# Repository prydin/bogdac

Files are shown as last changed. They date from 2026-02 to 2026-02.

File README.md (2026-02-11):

# BogDAC - A no frills DAC board for ES9039Q2M

## Introduction
I like to keep things simple. Reading about people "improving" their DACs with femtosecond-precision clocks, re-clockers, hundreds of farads of capacitance and potting soil (yes, potting soil), I decided I wanted to create a bog standard
DAC board based on the ES9039Q2M chip. I wanted a small board that would just accept an I2S stream and I2C commands and output single-ended audio. 

## Design Overview
This is following my Bog Standard concept: Keep things simple, follow best practices and avoid audiophile fads. The chip is locked into software mode and asynchronous I2S (a.k.a. PCM) operations using a local 49.152MHz oscillator. This 
allows for a design with a very simple and short clock signal path and should (at least in my opinion) perform better than external clocks connected through wires. The output section is pretty much just the one suggested in the data sheet and
based on OPA1612. The +/- 12V power for the analog section is provided by a TPS7A39 regulator. The 3.3V power for the analog reference voltages and the digital power is fed by a LT3046 regulator. The L3046 can be fed either from a separate 5V
power input or from the 12V rail by installing a jumper. Please note that nothing should be plugged into the 5V inlet if the jumper is installed.

## Schematic
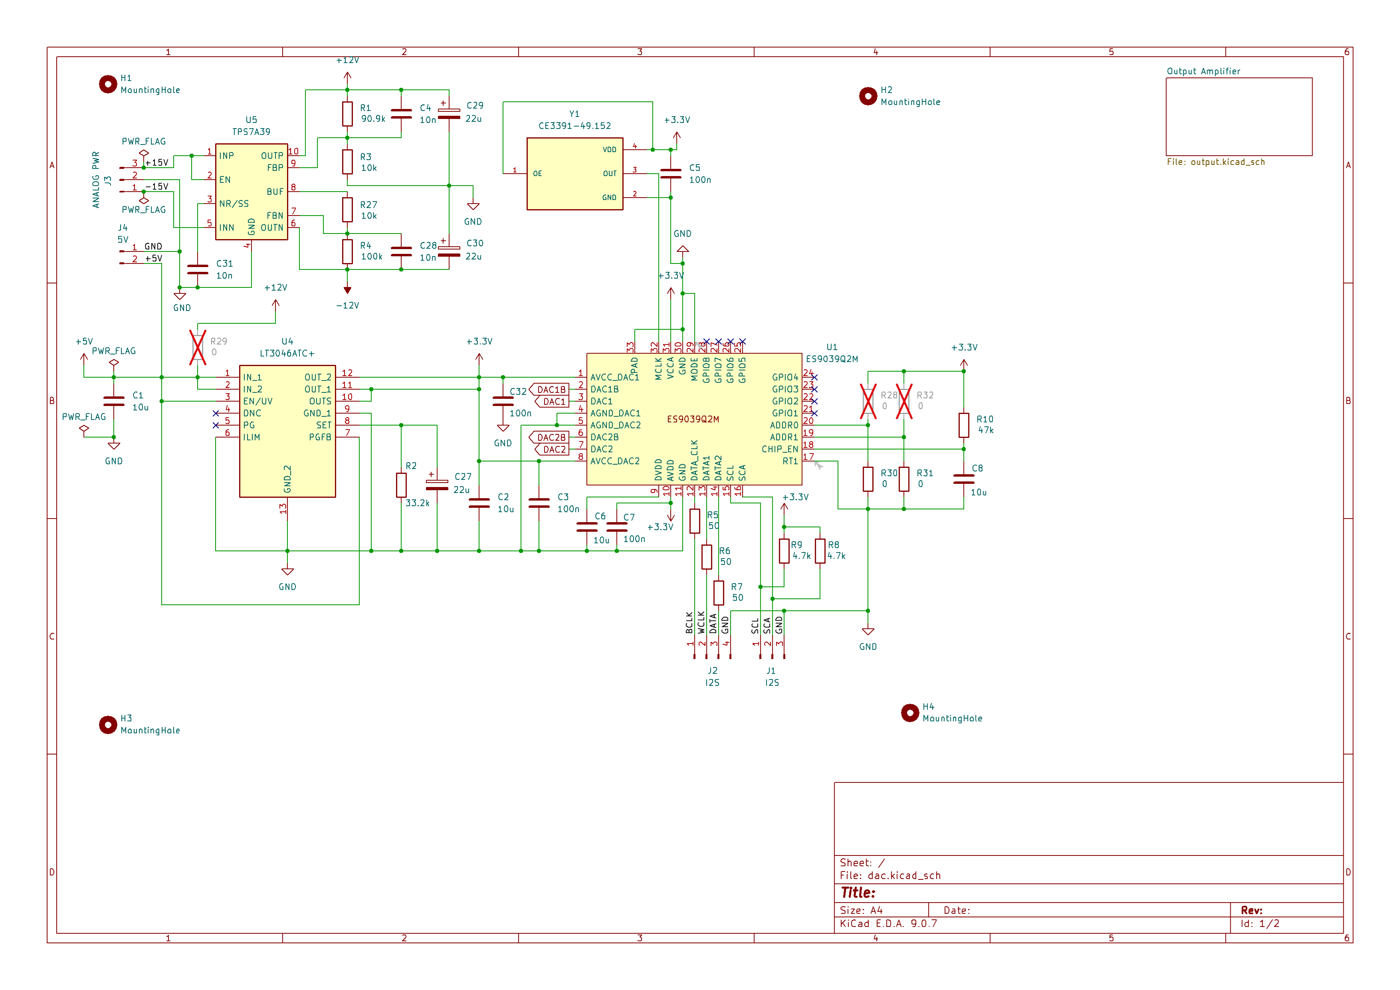
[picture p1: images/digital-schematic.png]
Digital schematic

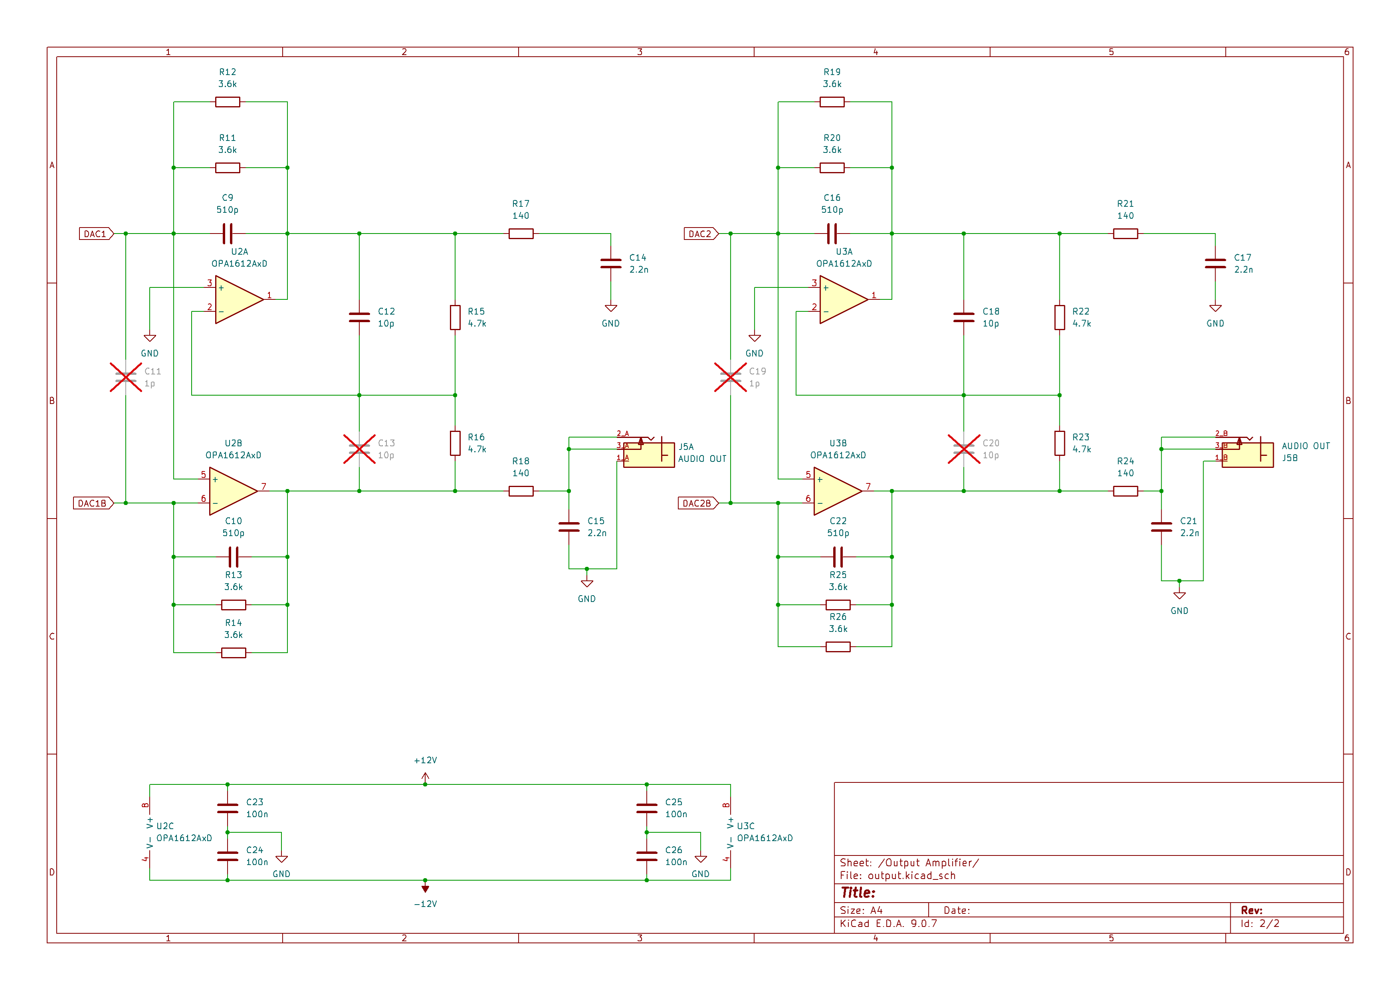
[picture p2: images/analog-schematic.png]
Analog schematic


## Test results
I tested this using a QA403. While this is a superb piece of gear, it has its limitations compared to test equipment that costs 100 times more. Because of this, the lower bound of the THD I can measure is about 0.0001% and the lowest noise 
floor is just above -150dBV. In fact, the harmonic profile of a loopback measurement looks very similar to the results I'm getting, so my hypothesis is that almost all noise and distortion you see comes from the measurement setup and 
not the circuit.

A 1kHz tone at full volume yields this spectrum. The THD is about 0.00013# and the SNR sits at about 113dB. I think the actual numbers are a lot better. Anyone who wants to lend me a $50,000 audio analyzer? :)


Another interesting measurement is looking at the idle noise. This is the DAC fully enabled, but without an input signal. I'm running the board on a cheap lab supply. As you can see, there's virtually no hum and very low noise.
You can thank those fancy regulators for that! 


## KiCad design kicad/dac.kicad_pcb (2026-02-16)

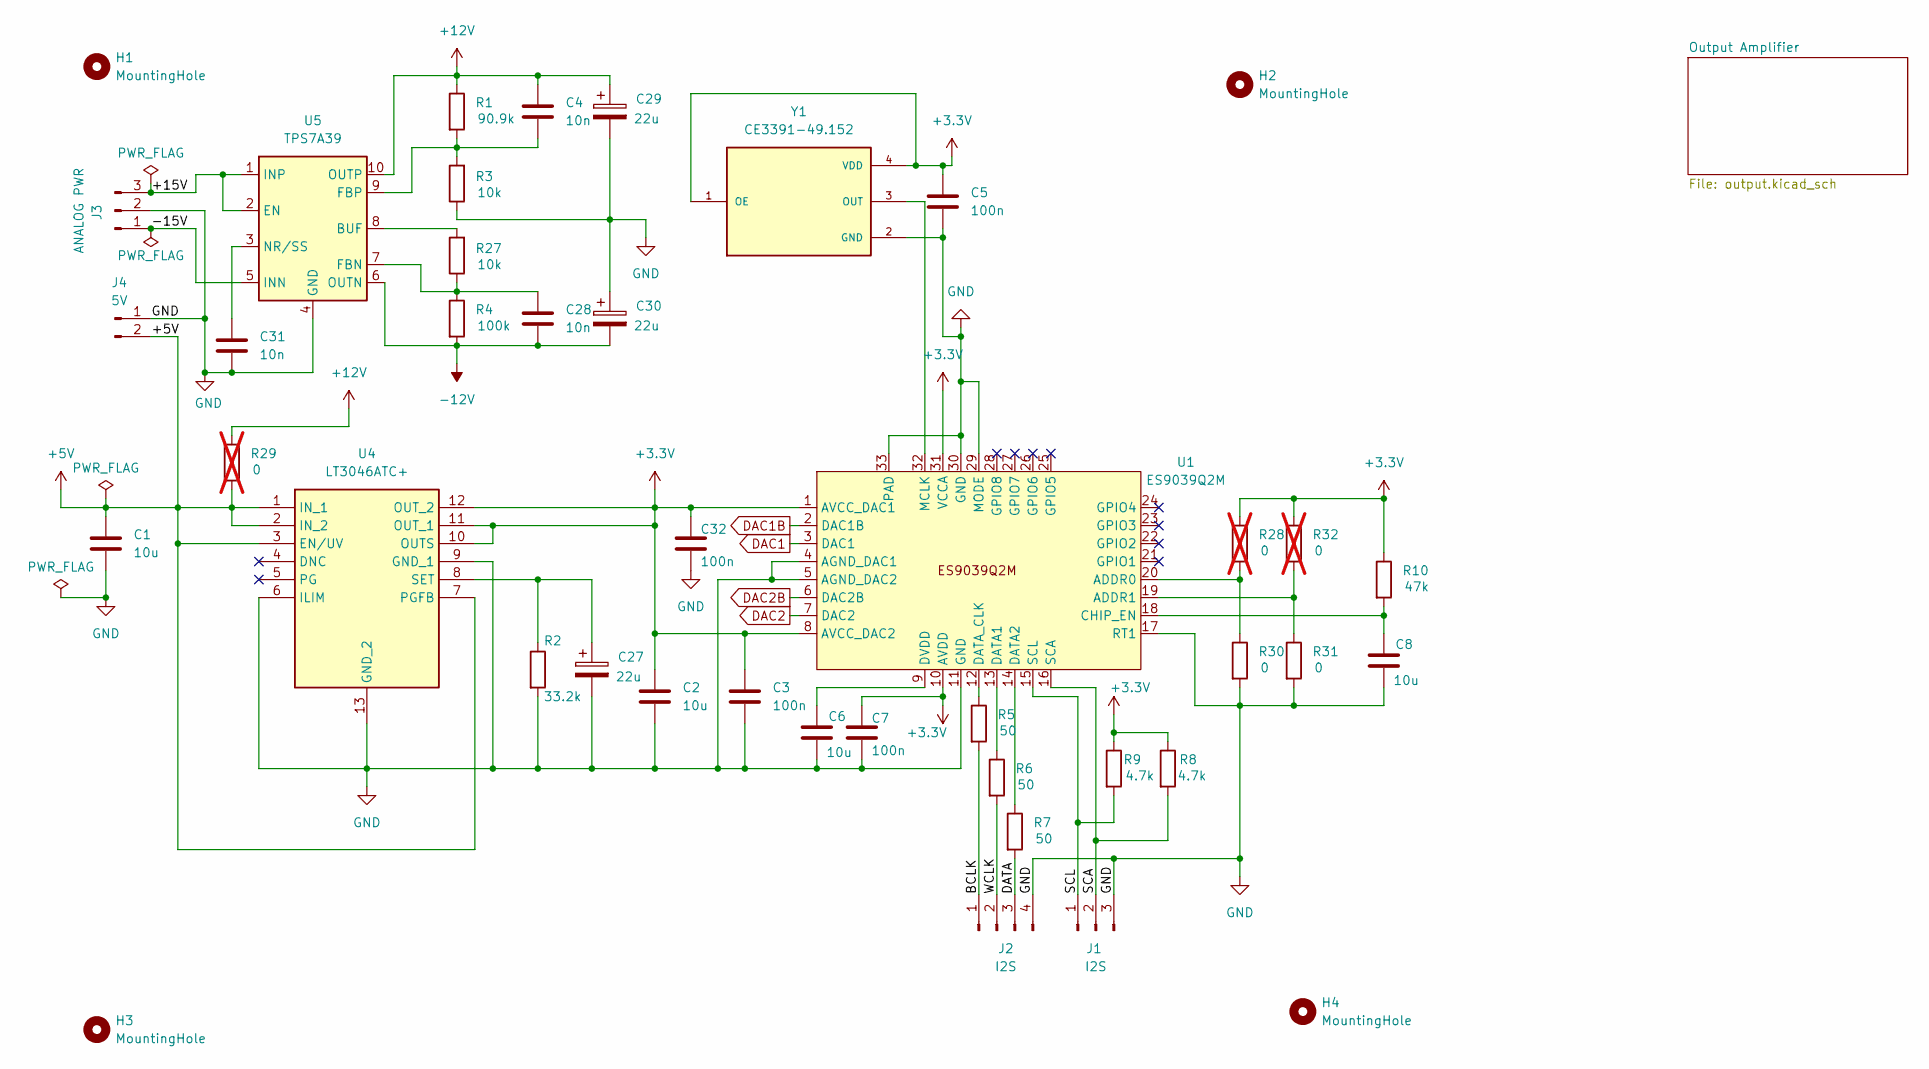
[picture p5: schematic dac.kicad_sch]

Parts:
C1, C2, C6, C8: 10u; C_0805_2012Metric
C3, C7, C32: 100n; C_0402_1005Metric
C4, C28, C31: 10n; C_0603_1608Metric
C5: 100n; C_0603_1608Metric
C27, C29, C30: 22u; CP_EIA-3216-10_Kemet-I_HandSolder
H1: MountingHole; MountingHole_3.2mm_M3
H2, H3, H4: MountingHole
J1: I2S; JST_PH_B3B-PH-K_1x03_P2.00mm_Vertical
J2: I2S; JST_PH_B4B-PH-K_1x04_P2.00mm_Vertical
J3: ANALOG PWR; JST_PH_B3B-PH-K_1x03_P2.00mm_Vertical
J4: 5V; JST_PH_B2B-PH-K_1x02_P2.00mm_Vertical
R1: 90.9k; R_0603_1608Metric_Pad0.98x0.95mm_HandSolder
R2: 33.2k; R_0603_1608Metric_Pad0.98x0.95mm_HandSolder
R3, R27: 10k; R_0603_1608Metric_Pad0.98x0.95mm_HandSolder
R4: 100k; R_0603_1608Metric_Pad0.98x0.95mm_HandSolder
R5, R6, R7: 50; R_0603_1608Metric_Pad0.98x0.95mm_HandSolder
R8, R9: 4.7k; R_0603_1608Metric_Pad0.98x0.95mm_HandSolder
R10: 47k; R_0603_1608Metric_Pad0.98x0.95mm_HandSolder
R28, R29, R32: 0; R_0603_1608Metric_Pad0.98x0.95mm_HandSolder; not fitted
R30, R31: 0; R_0603_1608Metric_Pad0.98x0.95mm_HandSolder
U1: ES9039Q2M; UFQFPN-32-1EP_5x5mm_P0.5mm_EP3.5x3.5mm
U4: LT3046ATC+; SON45P300X300X80-13N-D; Mouser Part Number 700-LT3046ATC+
U5: TPS7A39; Texas_S-PVSON-N10_ThermalVias
Y1: CE3391-49.152; Oscillator_SMD_Diodes_FN-4Pin_7.0x5.0mm; PARTREV NA

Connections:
+3.3V: C2.1, C3.1, C5.1, C7.1, C32.1, R8.1, R9.1, R10.1, R28.1, R32.1, U1.1 (AVCC_DAC1), U1.8 (AVCC_DAC2), U1.10 (AVDD), U1.31 (VCCA), U4.10 (OUTS), U4.11 (OUT_1), U4.12 (OUT_2), Y1.1 (OE), Y1.4 (VDD)
+5V: C1.1, J4.2, R29.2, U4.1 (IN_1), U4.2 (IN_2), U4.3 (EN/UV), U4.7 (PGFB)
+12V: C4.1, C29.1, R1.1, R29.1, U5.10 (OUTP); also elsewhere on the board
-12V: C28.2, C30.2, R4.2, U5.6 (OUTN); also elsewhere on the board
/+15V: J3.3, U5.1 (INP), U5.2 (EN)
/-15V: J3.1, U5.5 (INN)
/BCLK: J2.1, R5.2
/DATA: J2.3, R7.2
/SCA: J1.2, R8.2, U1.16 (SCA)
/SCL: J1.1, R9.2, U1.15 (SCL)
/WCLK: J2.2, R6.2
DAC1: U1.3 (DAC1); also elsewhere on the board
DAC1B: U1.2 (DAC1B); also elsewhere on the board
DAC2: U1.7 (DAC2); also elsewhere on the board
DAC2B: U1.6 (DAC2B); also elsewhere on the board
GND: C1.2, C2.2, C3.2, C5.2, C6.2, C7.2, C8.2, C27.2, C29.2, C30.1, C31.2, C32.2, J1.3, J2.4, J3.2, J4.1, R2.2, R3.1, R30.2, R31.2, U1.4 (AGND_DAC1), U1.5 (AGND_DAC2), U1.11 (GND), U1.17 (RT1), U1.29 (MODE), U1.30 (GND), U1.33 (PAD), U4.6 (ILIM), U4.9 (GND_1), U4.13 (GND_2), U5.4 (GND), U5.11 (GND), Y1.2 (GND); also elsewhere on the board
unnamed: R28.2, R30.1, U1.20 (ADDR0)
unnamed: R31.1, R32.2, U1.19 (ADDR1)
unnamed: C8.1, R10.2, U1.18 (CHIP_EN)
unnamed: R6.1, U1.13 (DATA1)
unnamed: R7.1, U1.14 (DATA2)
unnamed: R5.1, U1.12 (DATA_CLK)
unnamed: C6.1, U1.9 (DVDD)
unnamed: U1.32 (MCLK), Y1.3 (OUT)
unnamed: C27.1, R2.1, U4.8 (SET)
unnamed: R27.2, U5.8 (BUF)
unnamed: C28.1, R4.1, R27.1, U5.7 (FBN)
unnamed: C4.2, R1.2, R3.2, U5.9 (FBP)
unnamed: C31.1, U5.3 (NR/SS)

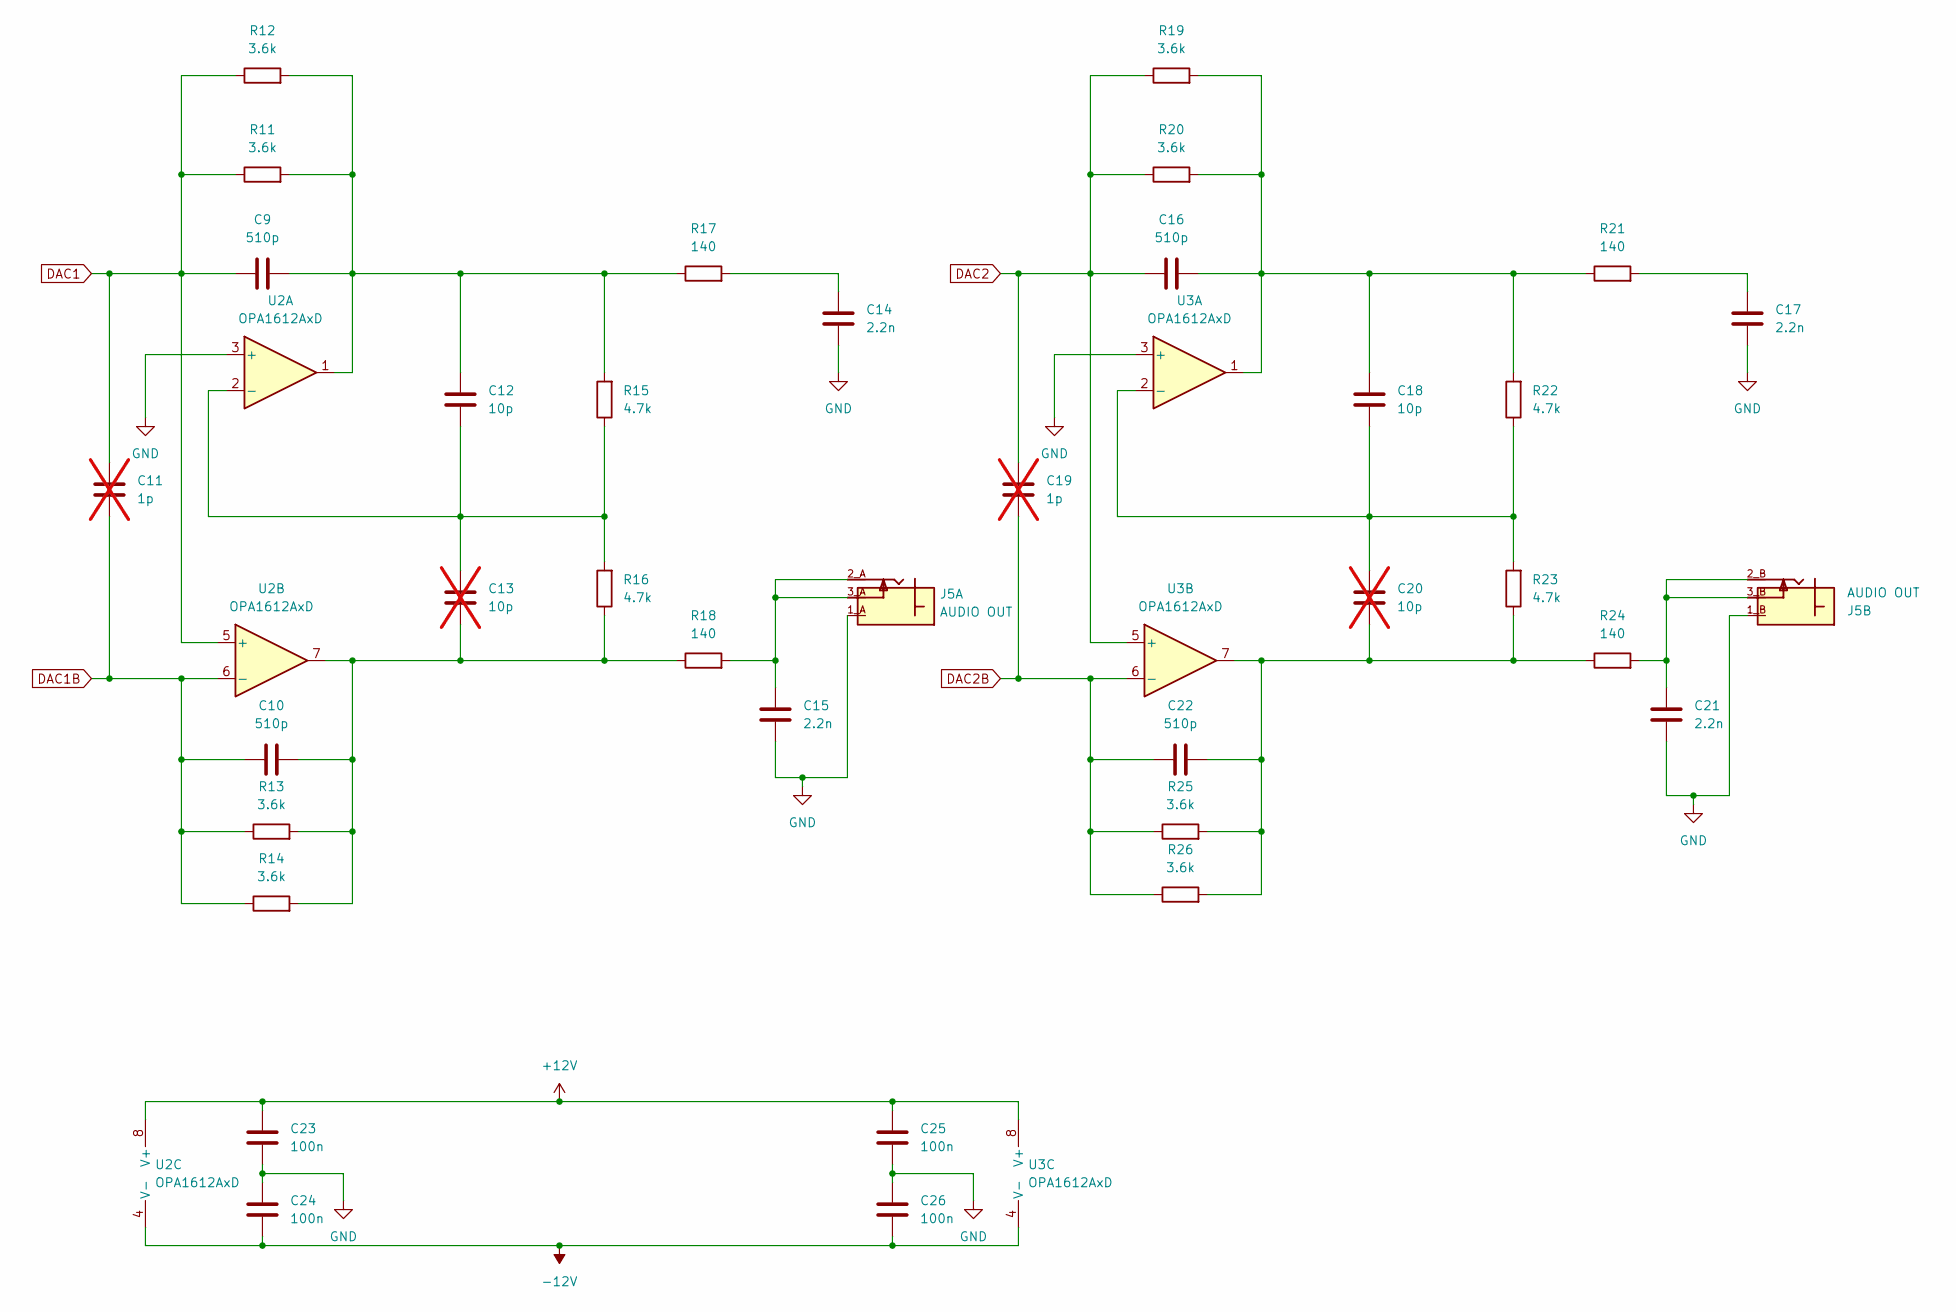
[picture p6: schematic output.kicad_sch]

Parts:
C9, C10, C16, C22: 510p; C_0603_1608Metric
C11, C19: 1p; C_0603_1608Metric; not fitted
C12, C18: 10p; C_0603_1608Metric
C13, C20: 10p; C_0603_1608Metric; not fitted
C14, C15, C17, C21: 2.2n; C_0603_1608Metric
C23, C24, C25, C26: 100n; C_0603_1608Metric
J5: AUDIO OUT; SWITCHCRAFT_PJRAN2X1U01AUX
R11, R12, R13, R14, R19, R20, R25, R26: 3.6k; R_0603_1608Metric_Pad0.98x0.95mm_HandSolder
R15, R16, R22, R23: 4.7k; R_0603_1608Metric_Pad0.98x0.95mm_HandSolder
R17, R18, R21, R24: 140; R_0603_1608Metric_Pad0.98x0.95mm_HandSolder
U2, U3: OPA1612AxD; SOIC-8_3.9x4.9mm_P1.27mm

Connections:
+12V: C23.2, C25.2, U2.8 (V+), U3.8 (V+); also elsewhere on the board
-12V: C24.1, C26.1, U2.4 (V-), U3.4 (V-); also elsewhere on the board
DAC1: C9.1, C11.2, R11.1, R12.1, U2.5 (+); also elsewhere on the board
DAC1B: C10.1, C11.1, R13.1, R14.1, U2.6 (-); also elsewhere on the board
DAC2: C16.1, C19.2, R19.1, R20.1, U3.5 (+); also elsewhere on the board
DAC2B: C19.1, C22.1, R25.1, R26.1, U3.6 (-); also elsewhere on the board
GND: C14.1, C15.1, C17.1, C21.1, C23.1, C24.2, C25.1, C26.2, J5.1_A, J5.1_B, U2.3 (+), U3.3 (+); also elsewhere on the board
unnamed: C10.2, C13.1, R13.2, R14.2, R16.1, R18.1, U2.7
unnamed: C9.2, C12.2, R11.2, R12.2, R15.2, R17.1, U2.1
unnamed: C14.2, R17.2
unnamed: C15.2, J5.2_A, J5.3_A, R18.2
unnamed: C16.2, C18.2, R19.2, R20.2, R21.1, R22.2, U3.1
unnamed: C17.2, R21.2
unnamed: C20.1, C22.2, R23.1, R24.1, R25.2, R26.2, U3.7
unnamed: C21.2, J5.2_B, J5.3_B, R24.2
unnamed: C12.1, C13.2, R15.1, R16.2, U2.2 (-)
unnamed: C18.1, C20.2, R22.1, R23.2, U3.2 (-)

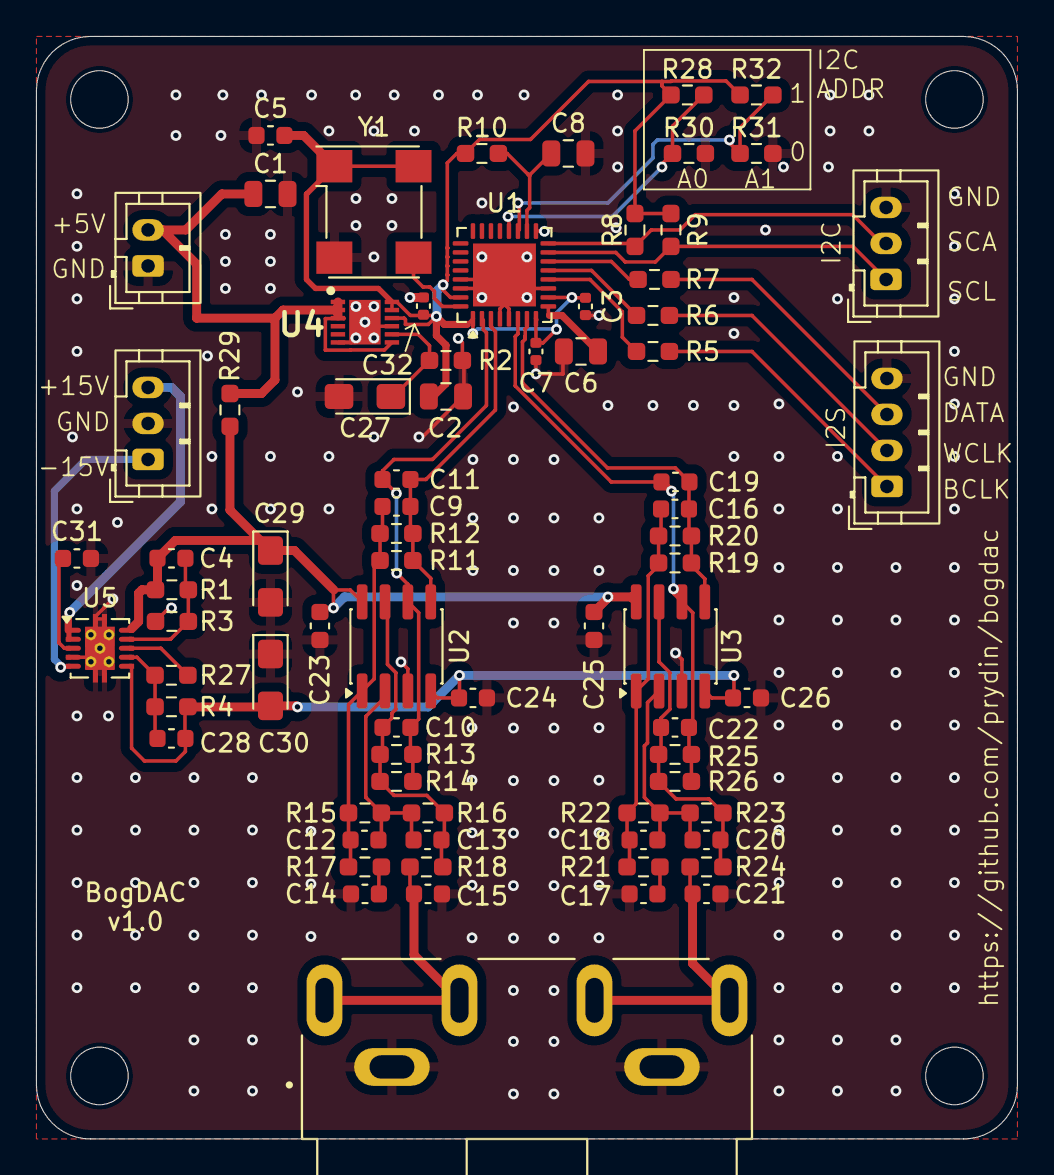
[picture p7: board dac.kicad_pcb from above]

Board: 4 copper layers, 54.5 x 61.2 mm, 79 parts (0 on the bottom side), 39 nets.

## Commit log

2026-02-08 Removed obsolete gerber files
    [dac-B_Cu.gbr, dac-B_Mask.gbr, dac-B_Paste.gbr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]
2026-02-10 Revise README with design overview and schematics
    Updated section headings and added schematic images.
2026-02-10 Added images and small PCB changes
2026-02-10 Change schematic images from JPG to PNG
    Updated schematic image formats from JPG to PNG.
2026-02-11 Added gerber
    [dac-B_Cu.gbr, dac-B_Mask.gbr, dac-B_Paste.gbr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]
